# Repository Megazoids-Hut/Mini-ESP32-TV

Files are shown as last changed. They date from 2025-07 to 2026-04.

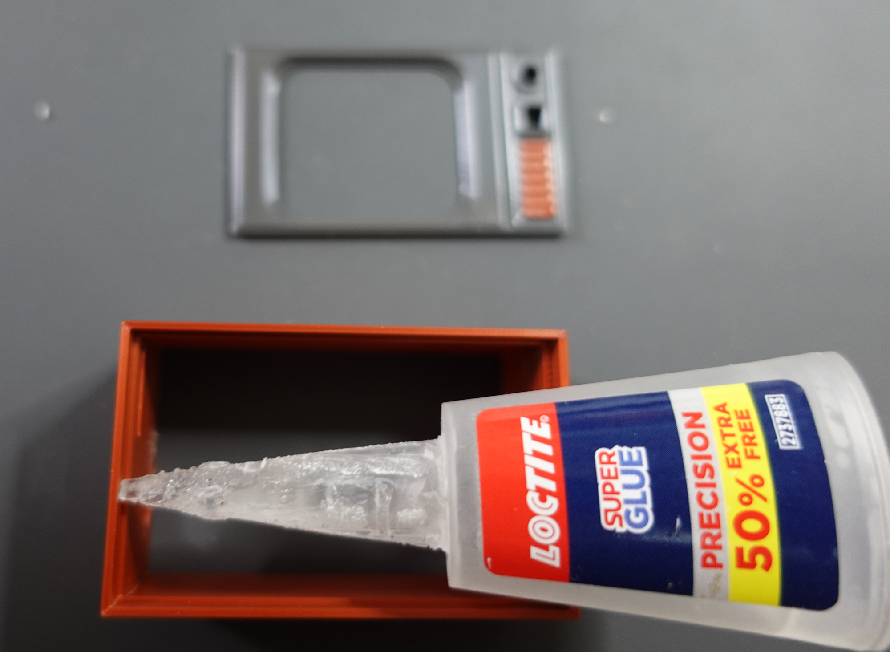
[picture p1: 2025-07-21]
images/32.jpg

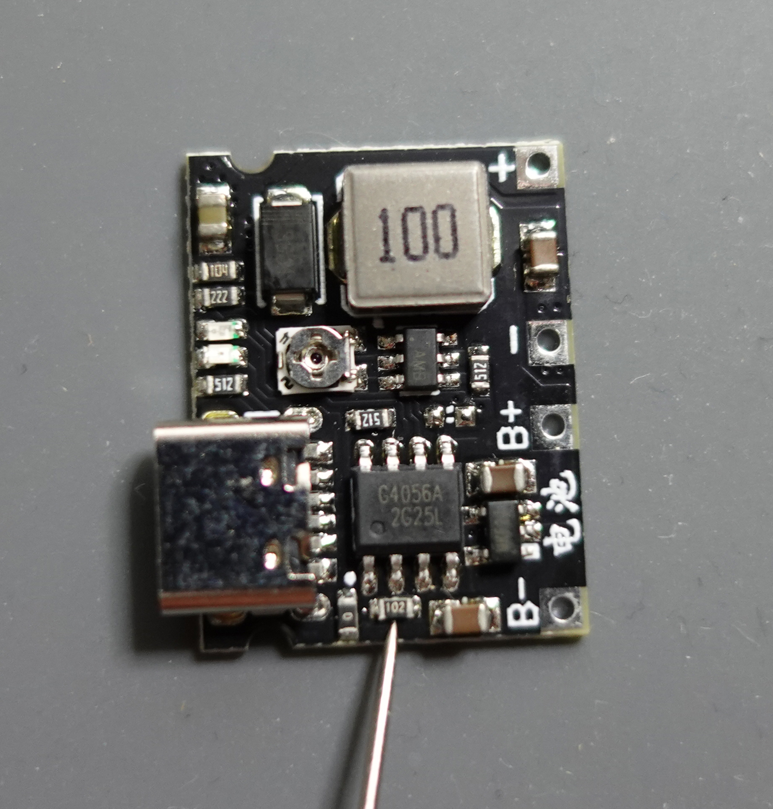
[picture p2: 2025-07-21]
images/6.JPG

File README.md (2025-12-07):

# Mini ESP32 TV (remix)

1_s

The project is a reworking of [Moononournation's Mini Retro TV](https://www.instructables.com/Mini-Retro-TV/). New case, PCB, code alterations for added fuctions (I had help!) and a movie file converter program. 

I've already splattered this project all over the Internet, but I wanted the files accessable on GitHub. It's posted on the following sites, which will have full build instructions :  
https://www.hackster.io/megazoid/mini-esp32-tv-remix-797a71  
https://www.instructables.com/Mini-ESP32-TV-remix  
https://www.thingiverse.com/thing:6330378  

> YouTube Demo : https://www.youtube.com/watch?v=mP0zoM2Ufms  

_________________________________  
  
# Supplies

5_s

1 x 1.69 Inch LCD display module (LCD Module - Square edges) [AliExpress](https://vi.aliexpress.com/item/1005003762571358.html)  
1 x D1 mini ESP32 - CH9102 Micro USB [AliExpress](https://vi.aliexpress.com/item/32816045916.html)  
1 x Max98357 I2S module [Aliexpress](https://vi.aliexpress.com/item/1005006711010527.html)  
4 x 10k SMD resistors (size 0805) 1/8W [Aliexpress](https://www.aliexpress.com/w/wholesale-10k-SMD-resistors-0805-1%252F8W.html)  
1 x 5.1k SMD resistors (size 0605) [Aliexpress](https://www.aliexpress.com/w/wholesale-5.1k-SMD-resistors-0603.html))  
1 x 9pin Micro SD card slot connector [LCSC.com](https://lcsc.com/product-detail/SD-Card-Connectors_G-Switch-GT-TF003-H0185-01_C5155563.html)  
1 x Battery Charger Boost Module TP4056 [Aliexpress](https://vi.aliexpress.com/item/1005005522998695.html)  
1 x 5.8x5.8x7mm Tactile Push Button Latching 6 Pin [AliExpress](https://vi.aliexpress.com/item/32948292577.html)  
1 x 6x6mm 9.5mm(total height) Momentary Push Button Switch [Aliexpress](https://www.aliexpress.com/w/wholesale-6x6mm-Momentary-Push-Button.html)  
1 x Ghxamp Mini Speaker 8Ohm 1W 34.8mm11.2mm6.0mm [Aliexpress](https://vi.aliexpress.com/item/33035261832.html)  
2 x M2*8mm Black Hex Countersunk Screws (total length 8mm) [Aliexpress](https://www.aliexpress.com/w/wholesale-M2-8mm-Black-Hex-Countersunk-Screws.html)  
1x Lithium battery 602535 or 603035 [Aliexpress](https://www.aliexpress.com/w/wholesale-Lithium-battery-602535.html)  
1 x Micro USB 4Pin Male Plug connector [Aliexpress](https://vi.aliexpress.com/item/32992732747.html)  
2 x 40-pin Header Pins 2.54mm Male Single Row [AliExpress](https://vi.aliexpress.com/w/wholesale-2-x-40%2525252dpin-Header-Pins-2.54mm-Male-Single-Row.html)  

Other Parts :  
1 x 32GB Micro SD Card  
Black and Red Silicone Wire (around 26AWG)  
Heat Shrink Tubing (optional)  
Brown, Black and Grey PLA+  

The PCB can be ordered from a PCB fabrication manufacturer Like JLBPCB : [Gerber File Zip](https://github.com/Megazoids-Hut/Mini-ESP32-TV/blob/main/gerber/Gerber_Mini_Esp32_Tv.zip) (Use default PCB board settings. 1.6mm thickness etc. Just upload the gerber zip and order)
Notes : When ordering parts, make sure they correspond with the ones in my pictures.For example there are two (or more) different 1.69 LCD displays out there, and many different D1 mini's  
  
_________________________________  
  
# Story

This Mini ESP32 TV project is remix of Moononournation's [Mini-Retro-TV](https://www.instructables.com/Mini-Retro-TV/) Instructable. I wanted to try something with a PCB, and the slightly cheaper D1 mini ESP32. It has a front facing on/off button, and a single multi function button that can change movie clips forwards and backward and mute the TV if needed.

**Licensing**: My PCB Gerber files and STLs are released under [The Unlicense](https://unlicense.org/). Everything else retains the licenses assigned by their creators.I take no responsibility for anything.

**Notes #1:** Some adjustment of the front panel STL might be needed to completely centre the LCD display module with the screen bezel.

**Notes #2:** The bin file's code source is unavailable.

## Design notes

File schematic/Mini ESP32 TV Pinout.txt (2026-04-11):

GPIO PINS
-----------
TFT DISPLAY 1.69"

5 = TFT CS
18 = SCL
22 = BLK
23 = SDA 
27 = DC
33 = RES

-----------
MAX98357A Audio Amplifier

25 = BCLK
26 = LCR
32 = DIN
-----------
Micro-SD-Reader

4 = MISO
13 = CS
14 = CLK
15 = MOSI
-----------
Function Button

21 = FUNC
-----------

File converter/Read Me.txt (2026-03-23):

====================================
Mini Retro TV - Video Convertor v0.4
====================================

1.  Open MiniTV_Converter_v0.4.exe

2.  Enter full YouTube URL, and click Download.
   ## Notes : This will download the highest resolution available and store it in am MP4 format. 
      It also works with other sites like Rumble, BitChute, Dailymotion etc. 

3.  The crop function will crop the video prior to conversion to mjpeg.
   ## Notes : This can handle 480p, 720p and 1080p videos only. Cropping can take
      some time (1 min. per 10 minutes of video approx).

4.  Select Video and Make Small, converts a movie to the Mini Retro TV format (288_30fps.mjpeg).

5.  Select Video to Extract Audio, will convert the movie to ACC audio (44100.aac)

5.1 Optional : Select the Decibel (dB) level of the clip. 
   ## Notes : I've dropped MY sound level to -8DB (the default) because I didn't use an additional 
      100k resistor on the MAX98357 audio board. If you have used a resistor, try a higher value. 
      Warning: Setting a very high level could cause distortion, and may even damage the speaker.

6. Transfer the 288_30fps.mjpeg and 44100.aac files to the Mini Retro TV microSD card. Either 
   create a new folder (and call it 4, or 5, or whatever number is next), or overwrite previous 
   files in one of the numbered folders.

*Final note: yt-dlp.exe may need periodic. There is an update button at the bottom of the GUI... or updating from : https://github.com/yt-dlp/yt-dlp

Coding by ChatGPT/Gemini CLI - Human assistant Megazoid

THE SOFTWARE IS PROVIDED "AS IS", WITHOUT WARRANTY OF ANY KIND,
EXPRESS OR IMPLIED, INCLUDING BUT NOT LIMITED TO THE WARRANTIES OF
MERCHANTABILITY, FITNESS FOR A PARTICULAR PURPOSE AND NONINFRINGEMENT.
IN NO EVENT SHALL THE AUTHORS BE LIABLE FOR ANY CLAIM, DAMAGES OR
OTHER LIABILITY, WHETHER IN AN ACTION OF CONTRACT, TORT OR OTHERWISE,
ARISING FROM, OUT OF OR IN CONNECTION WITH THE SOFTWARE OR THE USE OR
OTHER DEALINGS IN THE SOFTWARE.

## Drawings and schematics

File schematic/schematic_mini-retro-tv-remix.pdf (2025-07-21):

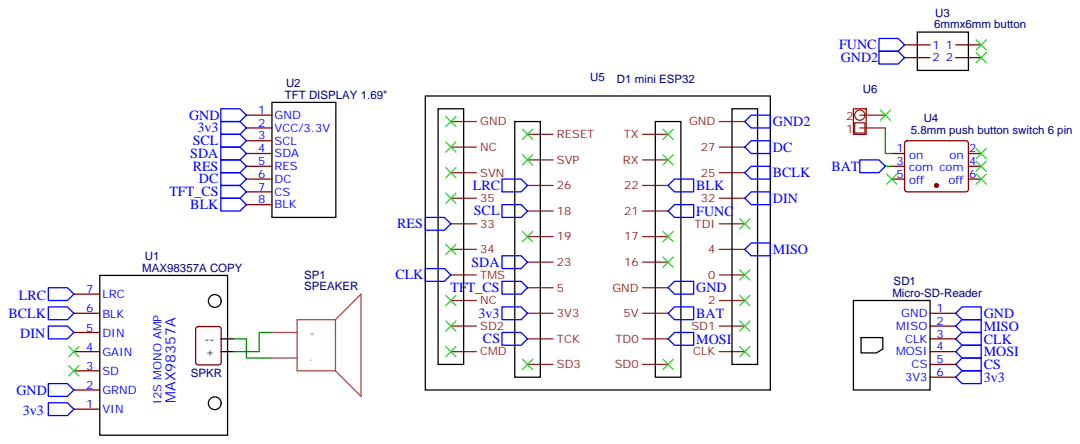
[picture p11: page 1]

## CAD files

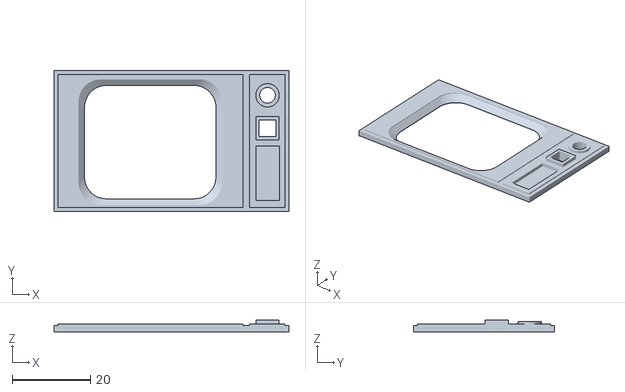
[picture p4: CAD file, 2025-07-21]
stl/front.stl
60.2 x 36.0 x 3.00

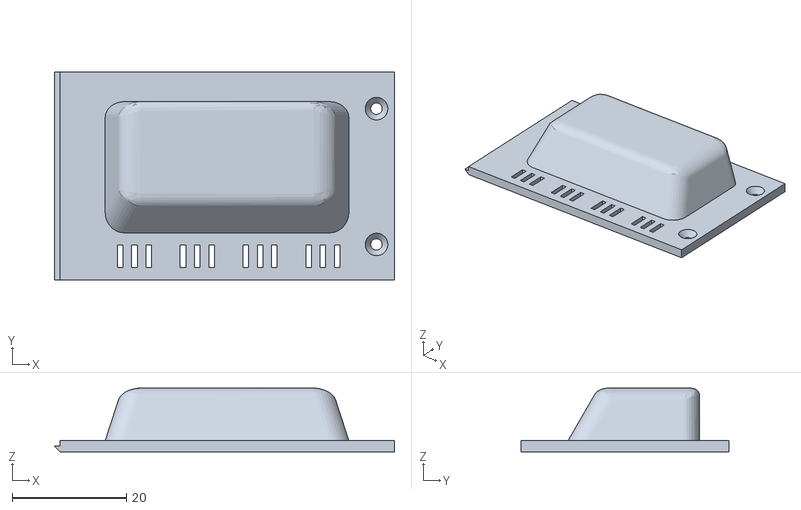
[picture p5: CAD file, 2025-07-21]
stl/back.stl
59.6 x 36.4 x 11.2

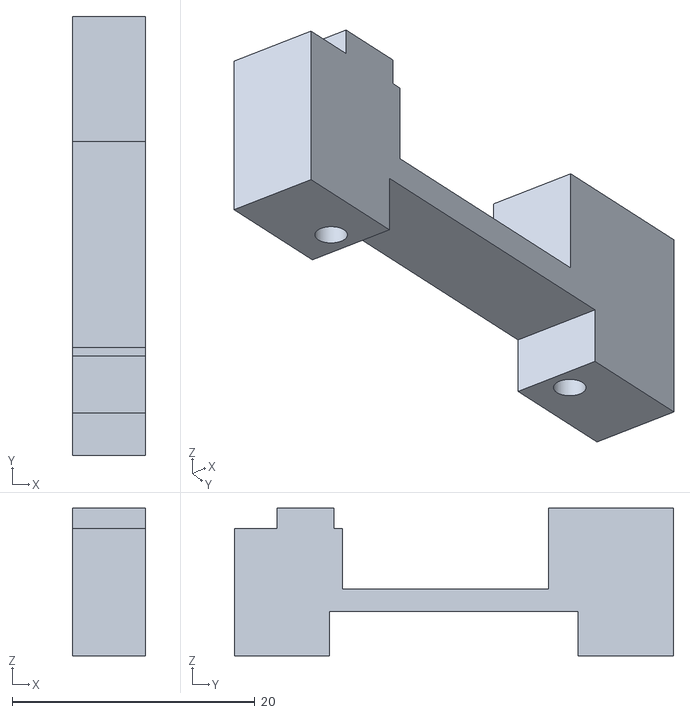
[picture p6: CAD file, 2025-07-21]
stl/back_holder.stl
6.00 x 36.2 x 12.2

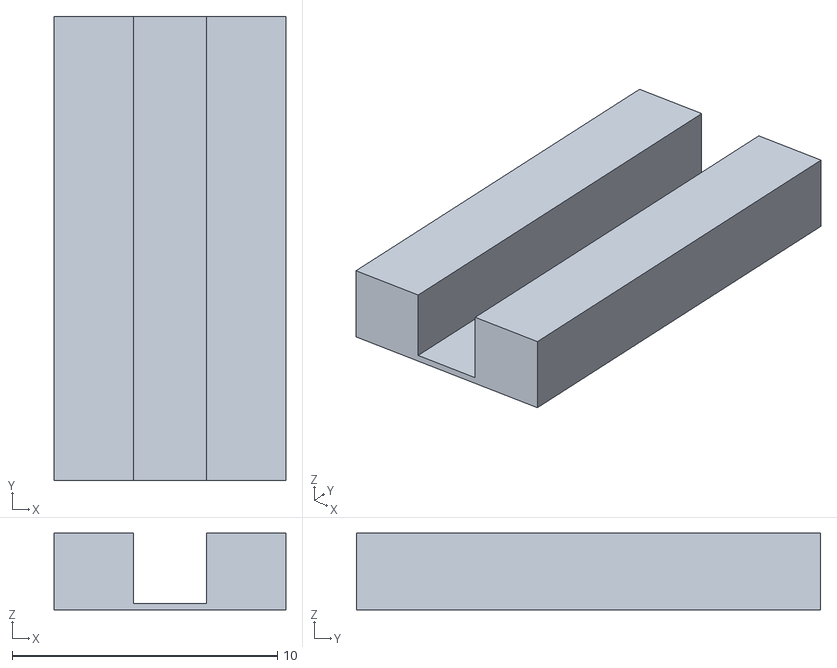
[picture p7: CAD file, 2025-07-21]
stl/spacers.stl
8.75 x 17.5 x 2.90

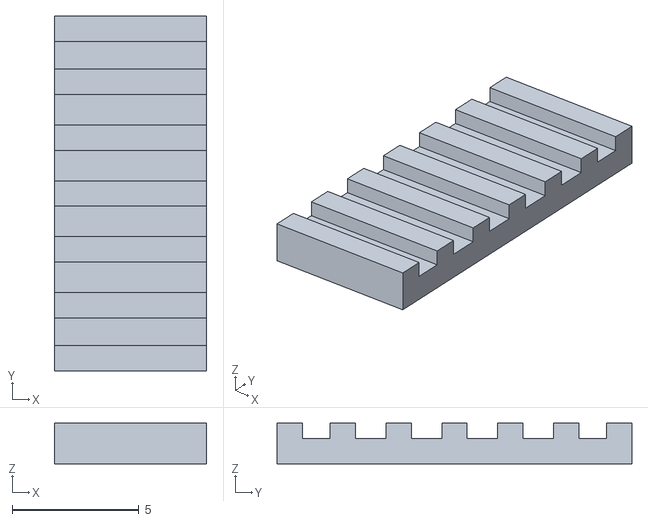
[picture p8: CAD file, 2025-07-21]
stl/grill.stl
6.00 x 14.0 x 1.60

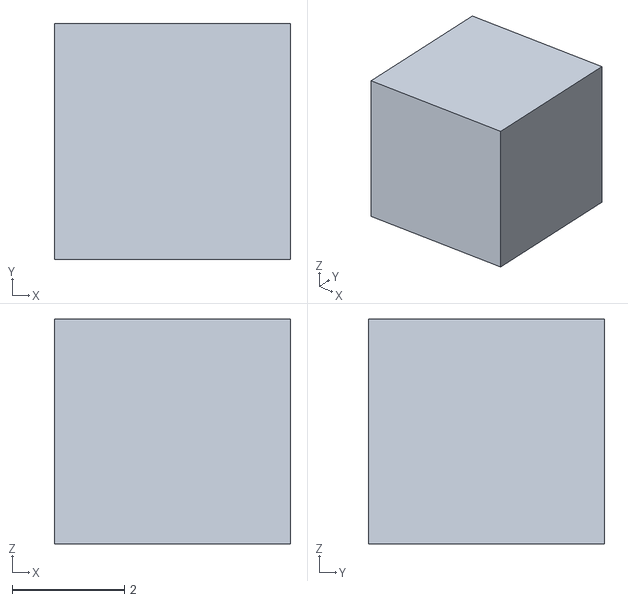
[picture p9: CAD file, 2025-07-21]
stl/button.stl
4.20 x 4.20 x 4.00

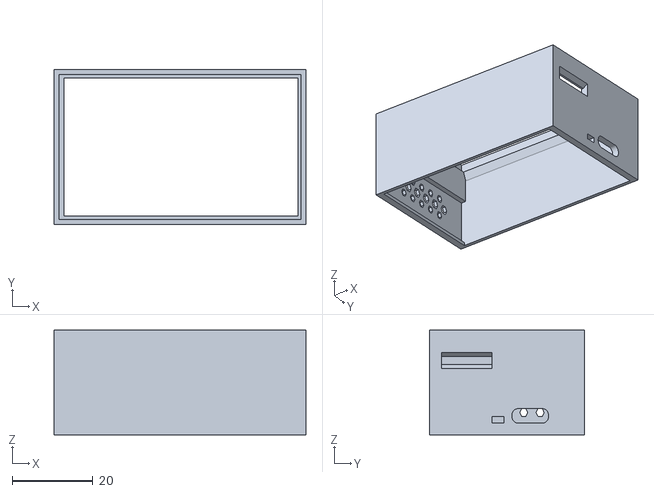
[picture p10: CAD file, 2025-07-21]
stl/body.stl
62.6 x 38.4 x 26.0

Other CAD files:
stl/front_v2.stl
